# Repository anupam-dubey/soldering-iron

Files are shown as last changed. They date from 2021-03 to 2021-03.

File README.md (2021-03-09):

# Temperature Cnntrolled soldering iron
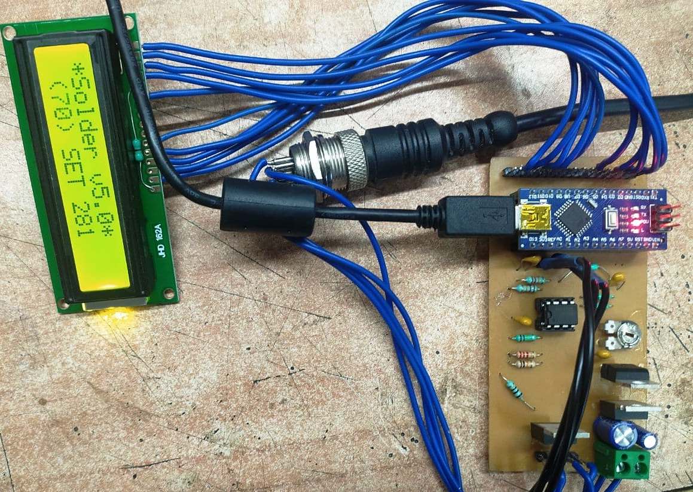
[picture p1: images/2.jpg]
</br> 
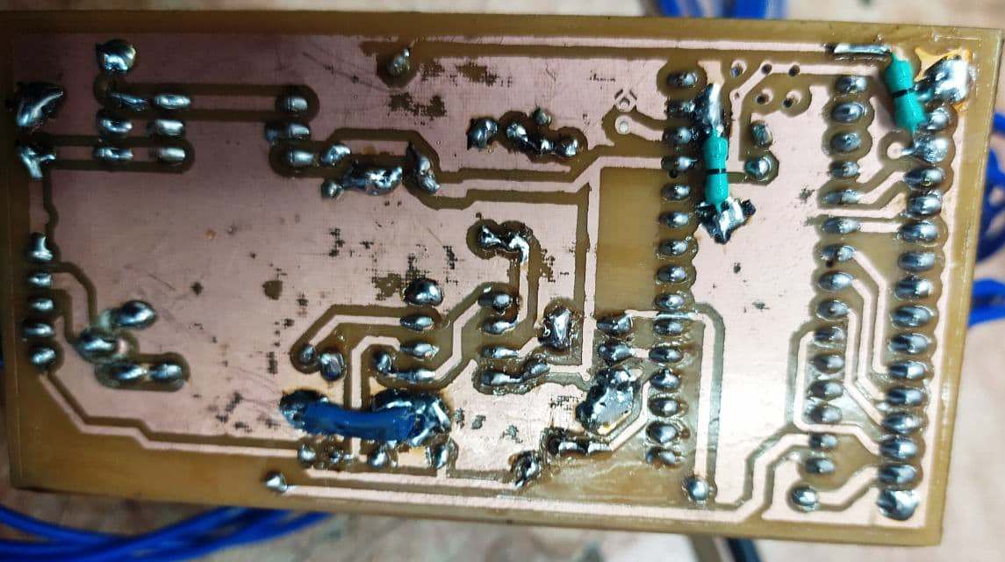
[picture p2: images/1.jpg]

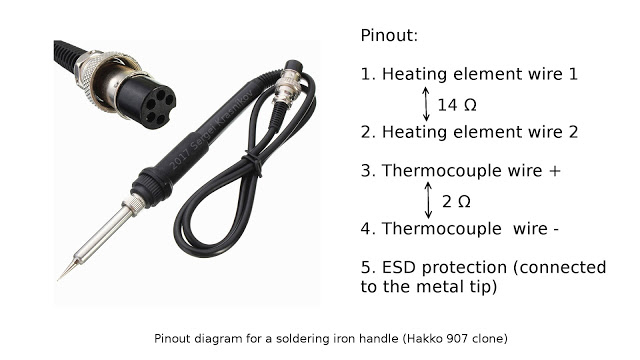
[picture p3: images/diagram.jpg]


## Description
USES popular nano mega328P ,The device controlles Temperature of  soldering iron based on hakko 907 models with inbuilt temperature sensor
Four Wires used in soldering iron contains heater and thermocouple sensor, heater wire is connected to arduino pin 11 for pwm via popular IRF44 mosfet
sensor wire goes to LM358 opamp for gain of 45 first stage and 2 for second stage gives a total gain of 90. It is adviced that before makeing this project be sure about thermocouple and heater wires and check the thermocouple using multimeter for determination of gain value. 
To calibrate the soldering station I use an external thermocouple with a multimeter that can measure temperatures. 
(Although other devices could be used)
The procedure consists of the following steps.
1. Rotate the soldering station's encoder to set a temperature value. Wait until the actual temperature stabilizes (the actual temperature = the set temperature). Let Xi be the set temperature.
2. Using an external thermocouple measure the temperature of the soldering iron's tip. Let Yi be the temperature measured by an external device.
3. Using different set temperatures repeat 1-2 steps a few times . i=1,2,...n
4. Now we have the set of points (X1,Y1),(X2,Y2),....,(Xn,Yn)
5. Find a function that maps Xi to Yi for all i=1,..,n.
If we have only 2 points (X1,Y1),(X2,Y2), then we can draw the line (Y=a*X+b) between the points. This line will be the solution to the problem.  If we have more than 2 points, we should use the method of least squares.
6. Use the function to convert ADC's numbers to actual temperatures.

|No |	Xi set temperature	|Yi temperature measured by an external device|
|---|	---	|---|
|1	|40 	|52|
|2	|80	 |95|
|3	|100 |125|
|4	|160	 |195|

We can use an online service to find the function.
Let's open wolframalpha.com. Then we should type the string "linear fit {40,52},{80,95},{100,125},{160,195}" in the edit box.
The solution for our problem is y= 1.202 x+2.56.
I used this function in the arduino's sketch to convert ADC's numbers to actual
temperatures.

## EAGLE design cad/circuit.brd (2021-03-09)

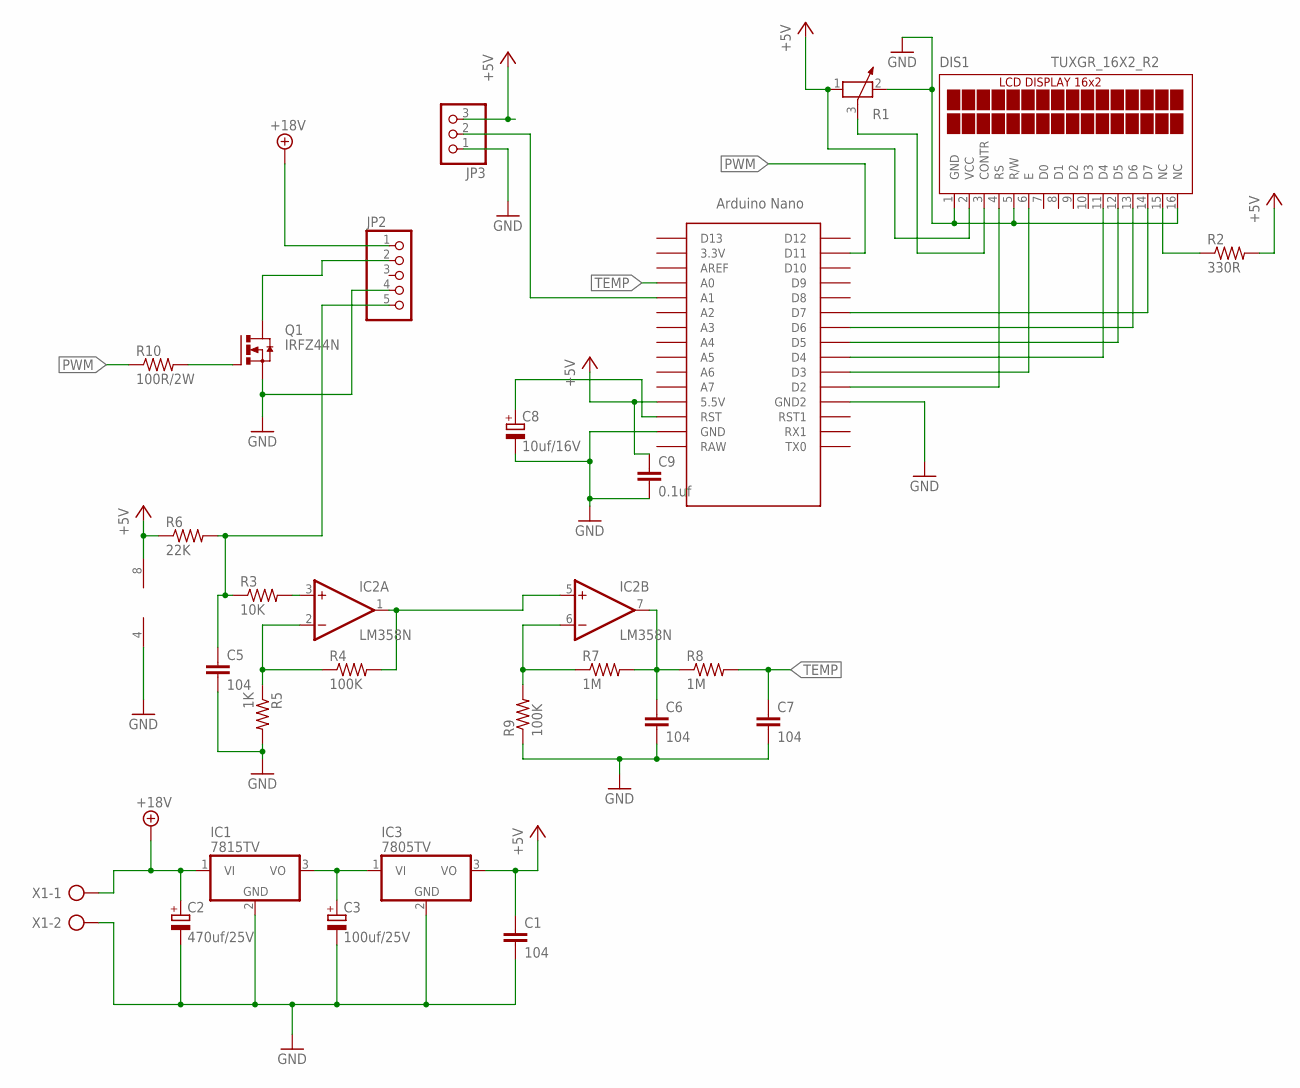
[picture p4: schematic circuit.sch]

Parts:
C1, C5, C6, C7: 104; C025-025X050
C2: 470uf/25V; E2,5-7
C3: 100uf/25V; E2,5-6
C8: 10uf/16V; E2-5
C9: 0.1uf; C025-040X050
DIS1: TUXGR_16X2_R2
IC1: 7815TV; TO220V
IC2: LM358N; DIL08
IC3: 7805TV; TO220V
JP2: PINHD-1X5; 1X05
JP3: PINHD-1X3; 1X03
Q1: IRFZ44N; TO220BV
R1: POTENTIOMETER_PT-10; PT-10
R2: 330R; 0207/10
R3: 10K; 0207/10
R4, R9: 100K; 0207/10
R5: 1K; 0207/10
R6: 22K; 0207/10
R7, R8: 1M; 0207/10
R10: 100R/2W; 0411/15
U$2: NANO
X1: AK500/2

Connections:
+5V: C1.1, C9.1, DIS1.2 (VCC), IC2.8 (V+), IC3.3 (VO), JP3.3, R1.1, R2.2, R6.1, U$2.5V (5.5V)
+18V: C2.+, IC1.1 (VI), JP2.1, X1.1
GND: C1.2, C2.-, C3.-, C5.2, C6.2, C7.2, C8.-, C9.2, DIS1.1 (GND), DIS1.5 (R/W), DIS1.16 (NC), IC1.2 (GND), IC2.4 (V-), IC3.2 (GND), JP2.4, JP3.1, Q1.S, R1.2, R5.2, R9.1, U$2.GND, U$2.GND1 (GND2), X1.2
unnamed: JP2.2, Q1.D
unnamed: IC2.1 (OUT), IC2.5 (+IN), R4.2
unnamed: C3.+, IC1.3 (VO), IC3.1 (VI)
unnamed: IC2.2 (-IN), R4.1, R5.1
unnamed: IC2.3 (+IN), R3.2
unnamed: DIS1.4 (RS), U$2.D2
unnamed: C5.1, JP2.5, R3.1, R6.2
unnamed: JP3.2, U$2.A1
unnamed: IC2.6 (-IN), R7.1, R9.2
unnamed: C6.1, IC2.7 (OUT), R7.2, R8.1
unnamed: Q1.G, R10.2
unnamed: DIS1.6 (E), U$2.D3
unnamed: C8.+, U$2.RST
unnamed: DIS1.11 (D4), U$2.D4
unnamed: DIS1.12 (D5), U$2.D5
unnamed: DIS1.13 (D6), U$2.D6
unnamed: DIS1.14 (D7), U$2.D7
unnamed: DIS1.3 (CONTR), R1.3
unnamed: DIS1.15 (NC), R2.1
PWM: R10.1, U$2.D11
TEMP: C7.1, R8.2, U$2.A0

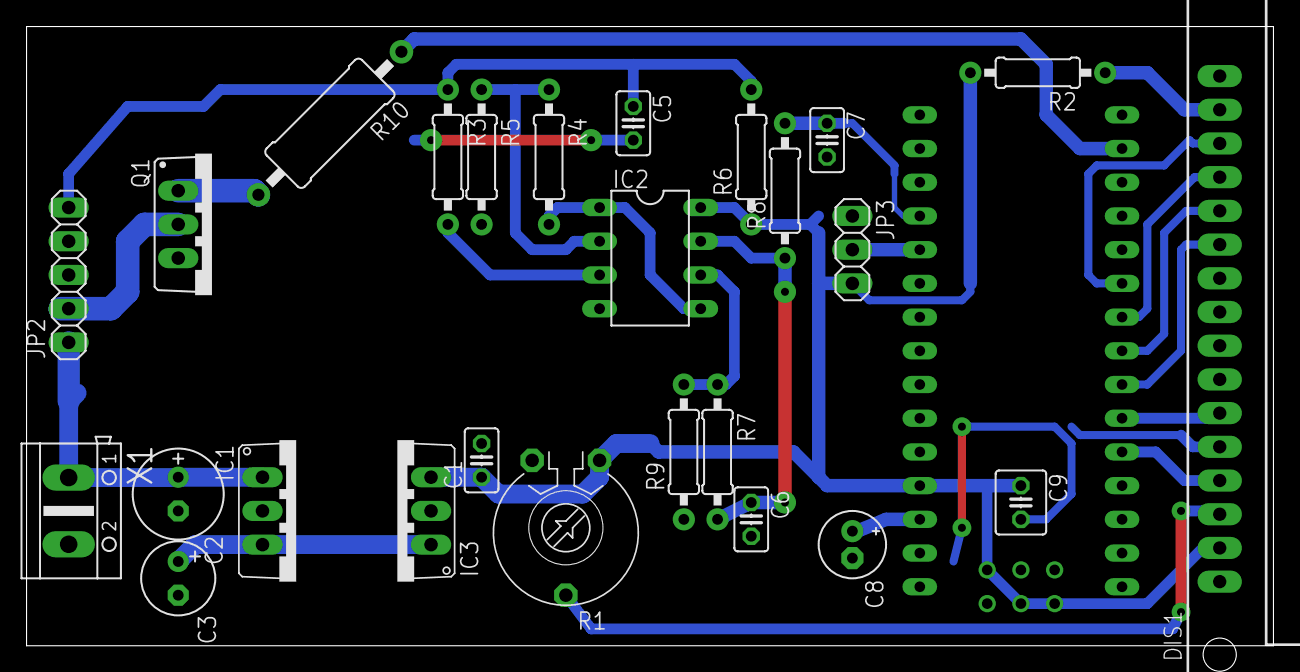
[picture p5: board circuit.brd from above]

Board: 2 copper layers, 94.0 x 46.7 mm, 27 parts (0 on the bottom side), 24 nets.

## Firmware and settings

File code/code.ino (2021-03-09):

#include <FastPID.h>              //Dwonload it here: https://www.electronoobs.com/eng_arduino_fastPID.php
#include <LiquidCrystal.h>

// initialize the library by associating any needed LCD interface pin
// with the arduino pin number it is connected to
const int rs = 2, en = 3, d4 = 4, d5 = 5, d6 = 6, d7 = 7;
LiquidCrystal lcd(rs, en, d4, d5, d6, d7);


/*PID variables. Fine tune this values. Start with P=1 and D and I = 0. Start increasing till you get good results*/
float Kp=7.98, Ki=0.055, Kd=0.86, Hz=10;          /*My values: Kp=7.98, Ki=0.055, Kd=0.86, Hz=10;*/
int output_bits = 8;                              //With 8 bits, maximum PID output is 255, and that's waht we need for analogWrite
bool output_signed = false;
FastPID myPID(Kp, Ki, Kd, Hz, output_bits, output_signed);

// adc variable
double CurrentTemp;
#define ADC_MULTISAMPLING 5
#define ADC_MULTISAMPLING_SAMPLES (1 << ADC_MULTISAMPLING)
// ao for tempread and d11 for mosfet heater

unsigned long currentMillis = 0;
unsigned long previousMillis = 0; 
//Inputs and outputs
int MOSFET_pin = 11;     //Pin that goes to the BJT that drives the n-MSOFET gate
/*int increase_pin = 7;   //Top button of the board (temperature increase)
int decrease_pin = 4;   //Bottomop button of the board (temperature decrease)
int vibrate = A1;       //Input from the vibrations sensor*/
int temp_sense = A0;    //Input from OPAMP (temperature read from thermocouple) My OPAMP gain is 201 (R1 = 1k, R2 = 200k)
int tr=0;
int tp=0;
float temperature_read,pot_read;
int   setpoint = 650;                            //Temperature setpoint initial value
float Delay=300; 
int td=0;
double read_pot()
{
   // Filter the ADC by multisampling with the values defined at the beginning
  int adc = 0;
  for (int i = 0; i < ADC_MULTISAMPLING_SAMPLES; ++i)
    adc += analogRead(A1);
    adc = adc >> ADC_MULTISAMPLING; 
  //Get the linear regression equations from excel data (Graph adc/temperature) (You need to perform real measures with externam thermometer) 
 double Input = map(adc, 0, 1023, 50, 500);
  // Additional filtering
//  CurrentTemp += (temp-CurrentTemp)*0.05;
//  return(CurrentTemp);
 return(Input);
}
float read_temperature()
{
   // Filter the ADC by multisampling with the values defined at the beginning
  int adc = 0;
  for (int i = 0; i < ADC_MULTISAMPLING_SAMPLES; ++i)
    adc += analogRead(temp_sense);
    adc = adc >> ADC_MULTISAMPLING; 
  //Get the linear regression equations from excel data (Graph adc/temperature) (You need to perform real measures with externam thermometer) 
 //double temp =  0.946*adc + 35;
   double temp = map(adc, 0, 700, 25, 350);
  // Additional filtering
  CurrentTemp += (temp-CurrentTemp)*0.02;
  return(CurrentTemp);
// return(adc);
}

void setup()
{ Serial.begin(115200);
  pinMode(MOSFET_pin,OUTPUT);
  
  digitalWrite(MOSFET_pin,LOW);
   lcd.begin(16, 2);
  // Print a message to the LCD.
  lcd.print("*Solder v5.0*");
 
  delay(1000);
  analogWrite(MOSFET_pin, 0);

}



void loop()
{
 int ms = 3;
 currentMillis = millis(); //First, we save the current elapsed time in milliseconds
 if (currentMillis - previousMillis >= Delay) 
 {
  previousMillis += Delay;
 temperature_read=read_temperature();
 tr=temperature_read;
 pot_read=read_pot();
 tp=pot_read;
 setpoint=tp;
 Serial.println("Temperature=");
 Serial.print(tr);
 /*PID part*/
    uint32_t before, after;
    before = micros();
    uint8_t output = myPID.step(setpoint, temperature_read);  
    after = micros();
    /*END of PID part*/
    if(output>150)
    output=150;
 
    analogWrite(MOSFET_pin, output);       
  /*Finally we write the PWM signal to the n-MOSFET
 
    Since we have a BJT driver at the n-MOSFET gate, we invert the signal (255 - output) where
    output is the PWM value from the PID control*/
 /*td++;
 if(td>180)
 {
  td=0;
  analogWrite(MOSFET_pin, 0);
  Serial.println("ok");
 }*/
 lcd.setCursor(1,1);
 lcd.write('(');
 lcd.print(tr);
  lcd.write(')');
 lcd.print(" SET ");
 lcd.print(setpoint);
 lcd.print("  ");
 }
 
 }
 
